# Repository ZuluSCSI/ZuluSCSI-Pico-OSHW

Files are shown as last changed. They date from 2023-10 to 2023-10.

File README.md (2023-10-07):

ZuluSCSI™ Pico Community Edition - Open Source Hardware
========================

This repository contains the KiCAD 7 schematic and PCB design files for the Pico-based ZuluSCSI™ SCSI to SD storage emulator, which is derived from the ZuluSCSI RP2040 board design. Firmware for ZuluSCSI is available at http://github.com/ZuluSCSI/ZuluSCSI-firmware.

This hardware design is licensed under the terms of the strongly reciprocal CERN OHL-S V2 license, which can be viewed in full at https://ohwr.org/cern_ohl_s_v2.txt and https://ohwr.org/cern_ohl_s_v2.pdf. 

ZuluSCSI™ is a registered trademark of Rabbit Hole Computing, and may not be used commercially without the express written consent of Rabbit Hole Computing. Individuals producing ZuluSCSI boards for personal use are hereby granted permission to use the ZuluSCSI trademark in a noncommercial capacity.

_Any_ use of the ZuluSCSI trademark in a **commercial** context requires prior written consent from Rabbit Hole Computing.

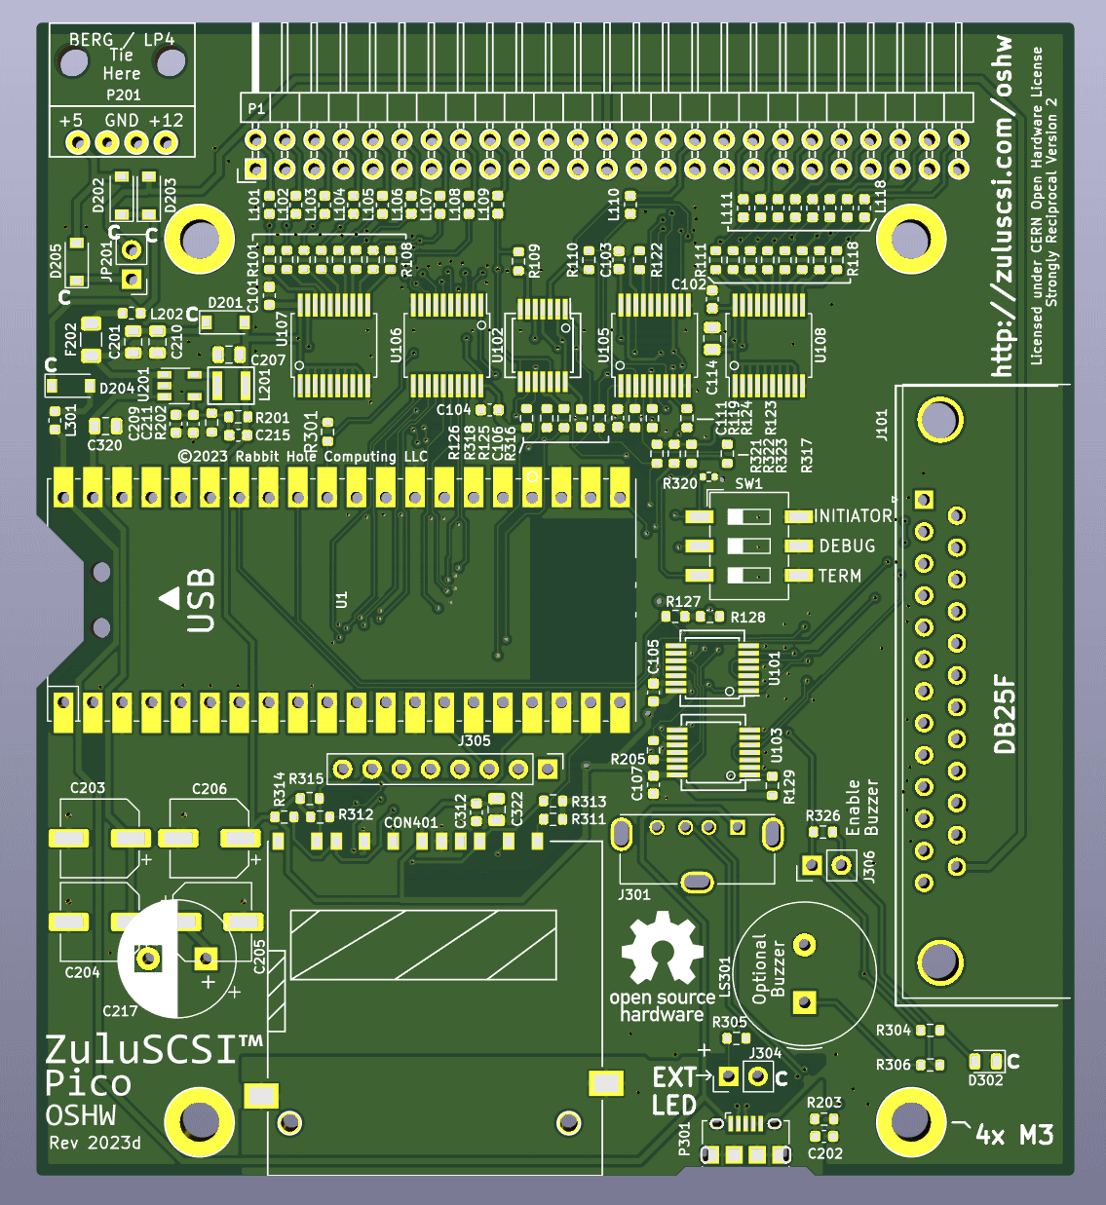
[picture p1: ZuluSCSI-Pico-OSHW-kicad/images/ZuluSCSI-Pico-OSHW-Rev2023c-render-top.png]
ZuluSCSI Pico OSHW board Render (top)


Generating fabrication files
----------------------------

The component part numbers are stored in KiCAD schematic.
Manufacturing files, including assembly BOM, can be generated using [KiKit](https://github.com/yaqwsx/KiKit).

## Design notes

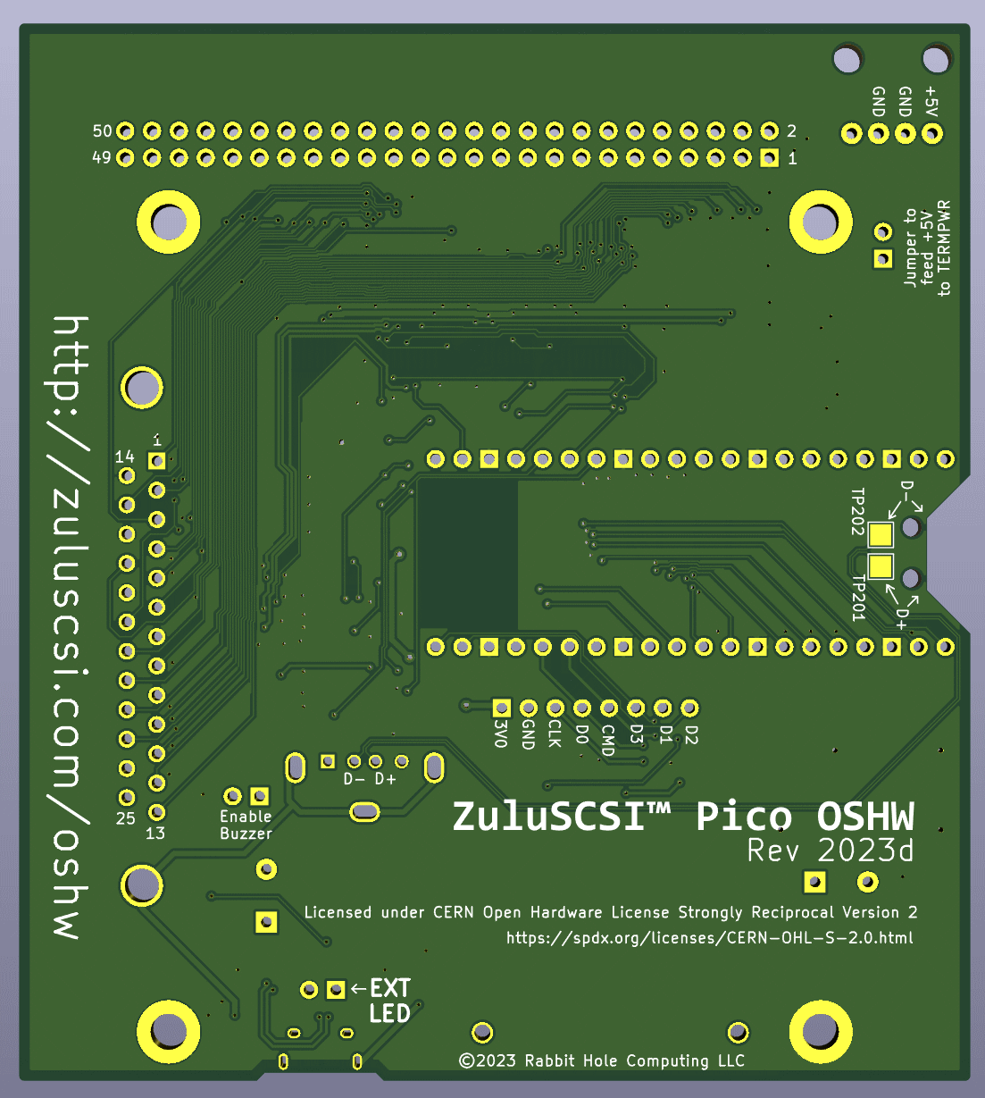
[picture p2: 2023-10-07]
ZuluSCSI-Pico-OSHW-kicad/images/ZuluSCSI-Pico-OSHW-Rev2023c-render-bottom.png

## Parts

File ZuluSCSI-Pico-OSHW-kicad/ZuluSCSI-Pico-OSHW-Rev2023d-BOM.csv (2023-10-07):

Designator | Footprint | Manufacturer P/N | Quantity | Value | LCSC P/N | Digi-Key P/N | Mouser P/N
C101, C102, C103, C104, C105, C106, C107, C202, C312 | 603 | CC0603KRX7R9BB104 | 9 | 100nF | C14663 | 311-1344-1-ND | 603-CC603KRX7R9BB104
C111, C209, C211, C215 | 603 | CL10C120JB8NNNC | 4 | 12pF | C38523 | 445-14057-1-ND | 187-CL10C120JB8NNNC
C114, C201, C207, C210, C320, C322 | 805 | CL21A106KAYNNNE | 6 | 10uF | C15850 | 1276-2891-1-ND | 187-CL21A106KAYNNNE
C203, C204, C205, C206 | CP_Elec_6.3x7.7 | RVT220UF16V67RV0015 | 4 | 220uF | C2887273 | 732-8422-1-ND | 710-865080345012
C217 | Radial through-hole D10.0mm by P5.00mm | UVY1C102MPD1TD | 1 | 1000uF | N/A | 493-14736-1-ND | 647-UVY1C102MPD1TD
CON401 | FCI 10067847-001 or SD-111 | SD-111 | 1 | SD Card Socket | C410353 | 609-3956-2-ND | 649-10067847-001RLF
D201, D202, D203, D204, D205 | SOD-123 | B5819W SL | 5 | D_Schottky | C8598 | SM5819PL-TPMSCT-ND | 833-SM5819PL-TP
D302 | 805 | SZYY0805YG | 1 | LED | C434435 | 350-2044-1-ND | 645-598-8170-107F
F202 | 1206 | JK-nSMD050-24 | 1 | 500mA Hold PTC | C369160 | 507-1802-1-ND | 530-0ZCJ0050FF2G
J101 | Optional DSUB-25 Female | D25S33E4PA00LF | 1 | N/A | N/A | 609-5879-ND | 649-D25S33E4PA00LF
J301 | Optional USB-A | Molex 105057 | 1 | N/A | N/A | WM8672-ND | 538-105057-0001
J304 | 2-pin 2.54mm Pin Header | Generic | 1 | Optional External LED header | N/A | 952-2262-ND | 855-M20-9990246
JP201 | 2-pin 2.54mm Pin Header | Generic | 0 | Optional Back Feed Jumper | N/A | 952-2262-ND | 855-M20-9990246
L101, L102, L103, L104, L105, L106, L107, L108, L109, L110, L111, L112, L113, L114, L115, L116, L117, L118, L202, L301 | 603 | GZ1608D601TF | 20 | 450mΩ ±25% 600Ω@100MHz | C1002 | 3442-GZ1608D601TFCT-ND | 815-ACML-0603H-601
L201 | 1008 | LQM2HPN2R2MG0L | 1 | 2.2uH | C86092 | 490-5114-1-ND | 81-LQM2HPN2R2MG0L
LS301 | Optional Piezo Buzzer | TDK PS1240P02BT | 1 | N/A | C76871 | 445-2525-1-ND | 810-PS1240P02BT
P1 | 50-pin right angle IDC (SCSI) | Z-231012050106 | 1 | 2X25 right angle box header | C221060 | 3M157291-ND | 30350-5002HB
P201 | Optional Floppy power connector | 171826-4 | 1 | Floppy-style BERG/LP4 | C590635 | A112643-ND | 571-1718264
P301 | Optional USB Micro-B | 10118194-0001LF | 1 | Micro USB OTG (optional) | C132563 | 609-4618-1-ND | 649-10118194-0001LF
R101, R102, R103, R104, R105, R106, R107, R108, R109, R110, R111, R112, R113, R114, R115, R116, R117, R118, R119 | 603 | 0603WAF1100T5E | 19 | 110 | C22781 | 311-4.70KHRCT-ND | 603-RC0603FR-074K7L
R122, R123, R124, R125, R301, R321, R322, R323 | 603 | 0603WAF1001T5E | 8 | 1k | C21190 | 13-AC0603FR-131KLCT-ND | 603-AC0603FR-131KL
R126, R127, R128, R129, R205, R311, R312, R313, R314, R315, R316, R317, R318 | 603 | 0603WAF4701T5E | 13 | 4k7 | C23162 | 311-4.70KHRCT-ND | 603-RC0603FR-074K7L
R201 | 603 | 0603WAF5103T5E | 1 | 510k | C23192 | 311-510KHRCT-ND | 603-RC0603FR-07510KL
R202, R203 | 603 | 0603WAF1003T5E | 2 | 100k | C25803 | 311-100KHRCT-ND | 603-RC0603FR-07100KL
R304, R305, R306 | 603 | 0603WAJ0620T5E | 3 | 62 | C25252 | 311-62.0HRCT-ND | 603-RC0603FR-0762RL
R320 | 402 | N/A | 0 | None (DNP) | N/A | N/A | N/A
SW1 | DIP slide switch, SPSTx03 | DSIC03LS-P | 1 | SW_DIP_x03 | C319040 | CT2043ST-ND | 774-2043ST
U1 | Raspberry Pi Pico (Pico, Pico H, or Pico W) | Pico | 1 |  | N/A | N/A | N/A
U101, U102, U103 | SSOP or TSSOP | SN74LVTH125PWR | 3 | 74LVT125 | C7042 | 296-8660-1-ND | 595-SN74LVTH125PWR
U105, U106, U107, U108 | SSOP or TSSOP | SN74LVTH245APWR | 4 | 74LVT245 | C7057 | 296-48966-1-ND | 595-SN74LVTH245APWR
U201 | TSOT-23-5 | LM3674MFX-ADJ/NOPB | 1 | LM3674-ADJ | C882787 | 296-43049-1-ND | 926-LM3674MFXADJNOPB

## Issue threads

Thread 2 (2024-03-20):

Expansion header

badass-boss, 2024-03-20:
Does this hardware revision offer expansion header? Is this possible to attach DAC Attack board to it?

aperezbios, 2024-03-27:
@badass-boss it does not. In order for there to be sufficient I/O's for the DAC Attack add-on board, you must be using a ZuluSCSI RP2040 (non-Pico) board, as the pinouts are slightly different. The RP2040 is a great chip, but it comes with limitations, particularly on the limited I/O front.

Closed 2024-03-27.

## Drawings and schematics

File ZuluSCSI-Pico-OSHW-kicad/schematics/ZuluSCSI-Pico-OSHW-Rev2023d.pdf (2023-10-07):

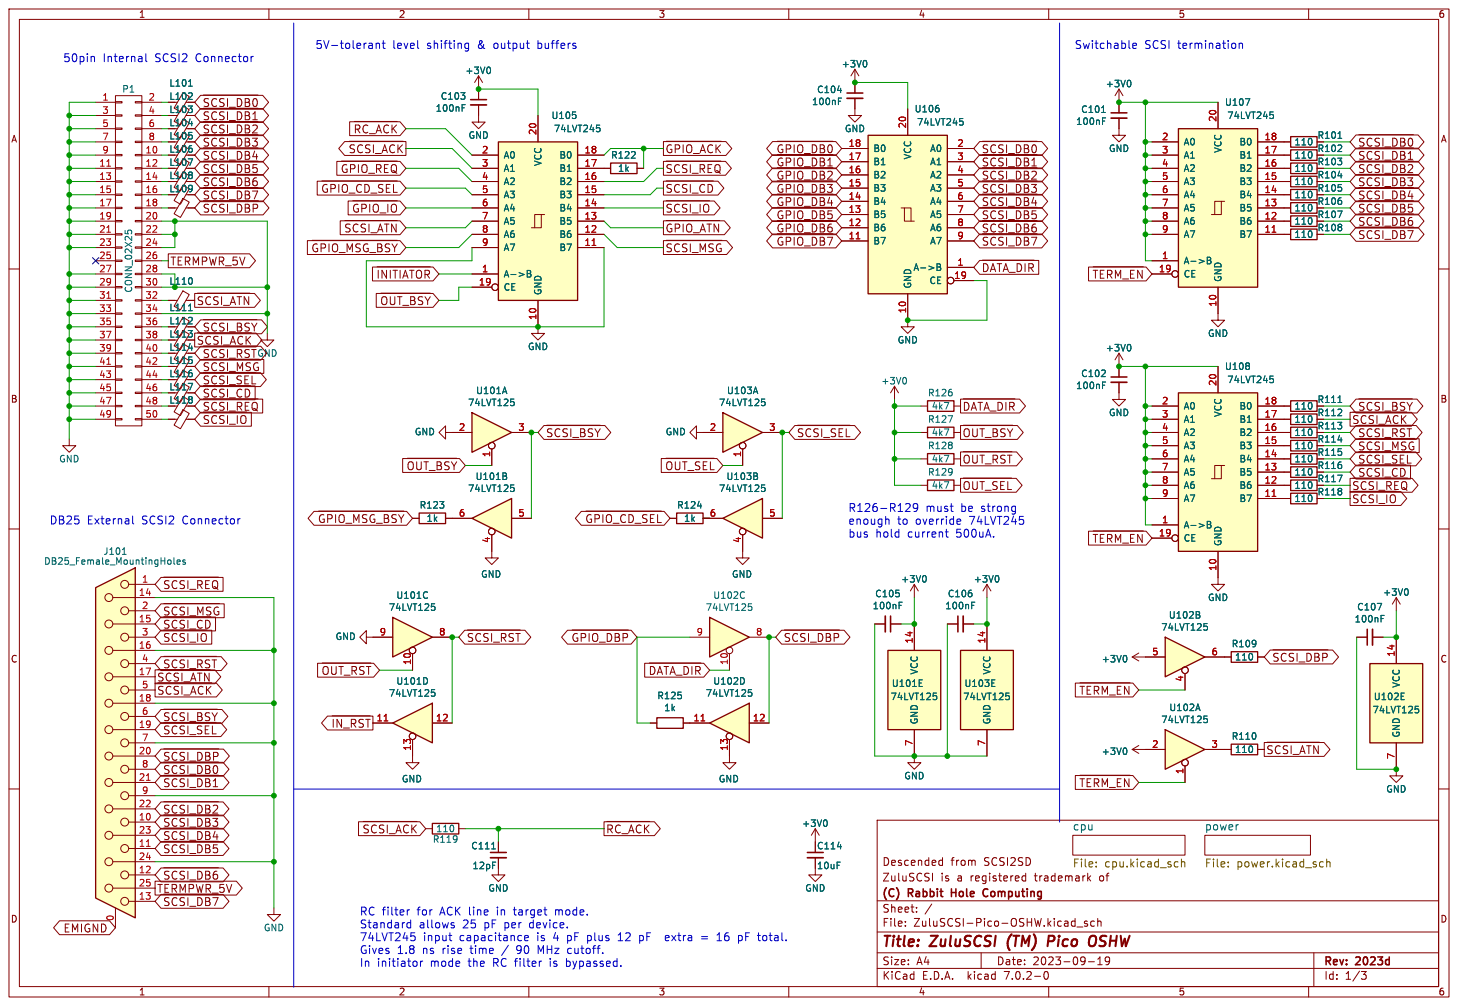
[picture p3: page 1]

Id: 1/3 Title: ZuluSCSI (TM) Pico OSHW

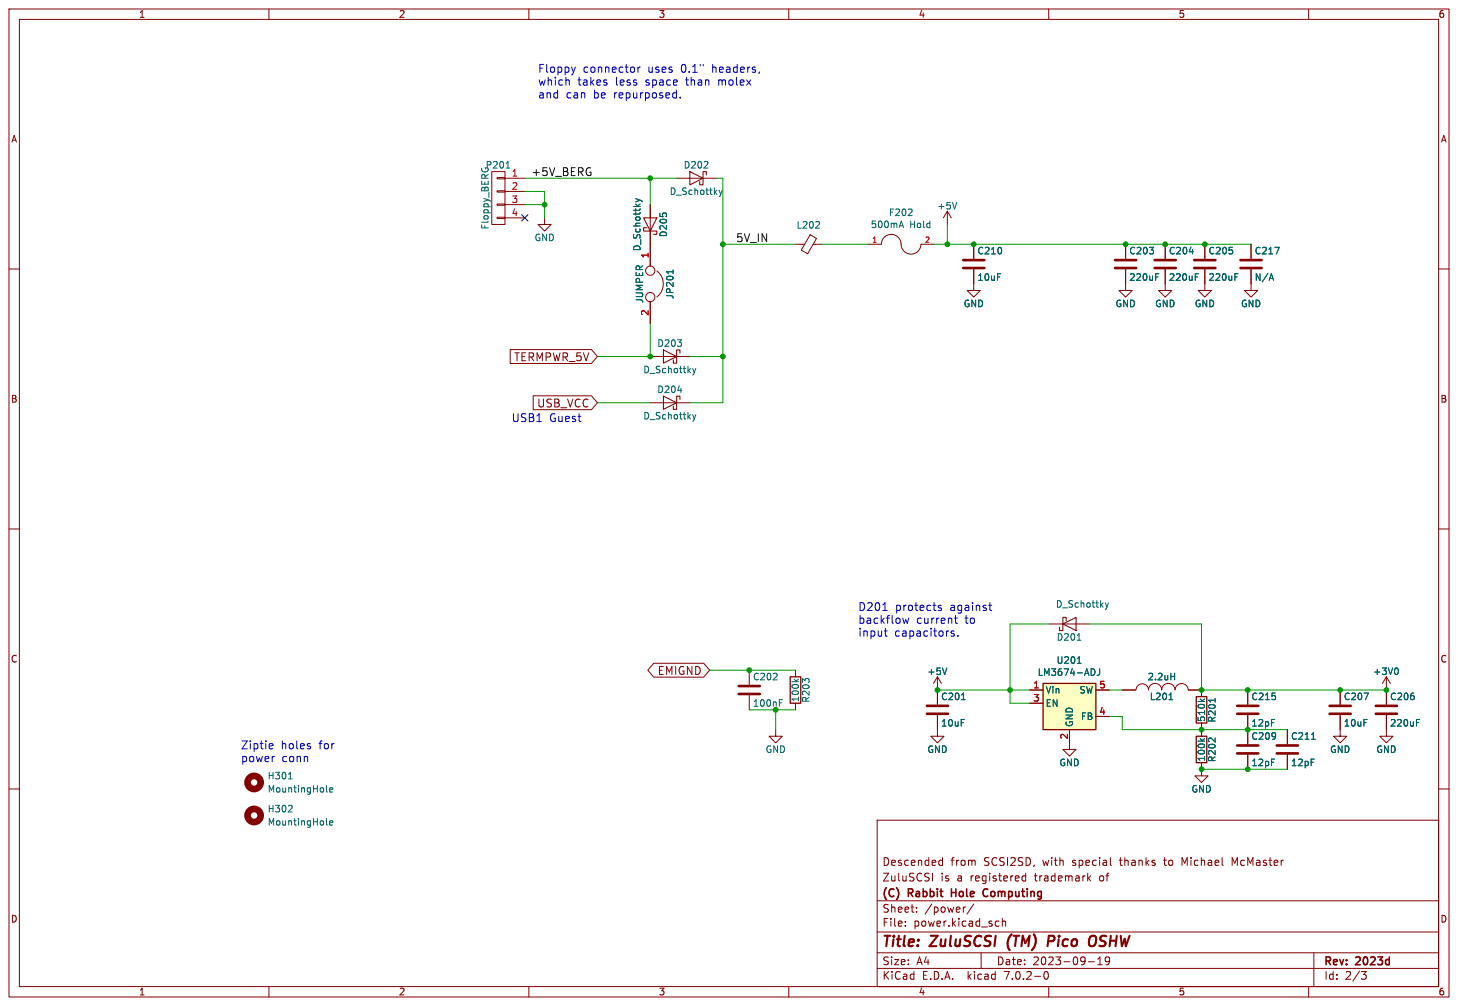
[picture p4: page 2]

D201 protects against backflow current to

Id: 2/3 Title: ZuluSCSI (TM) Pico OSHW

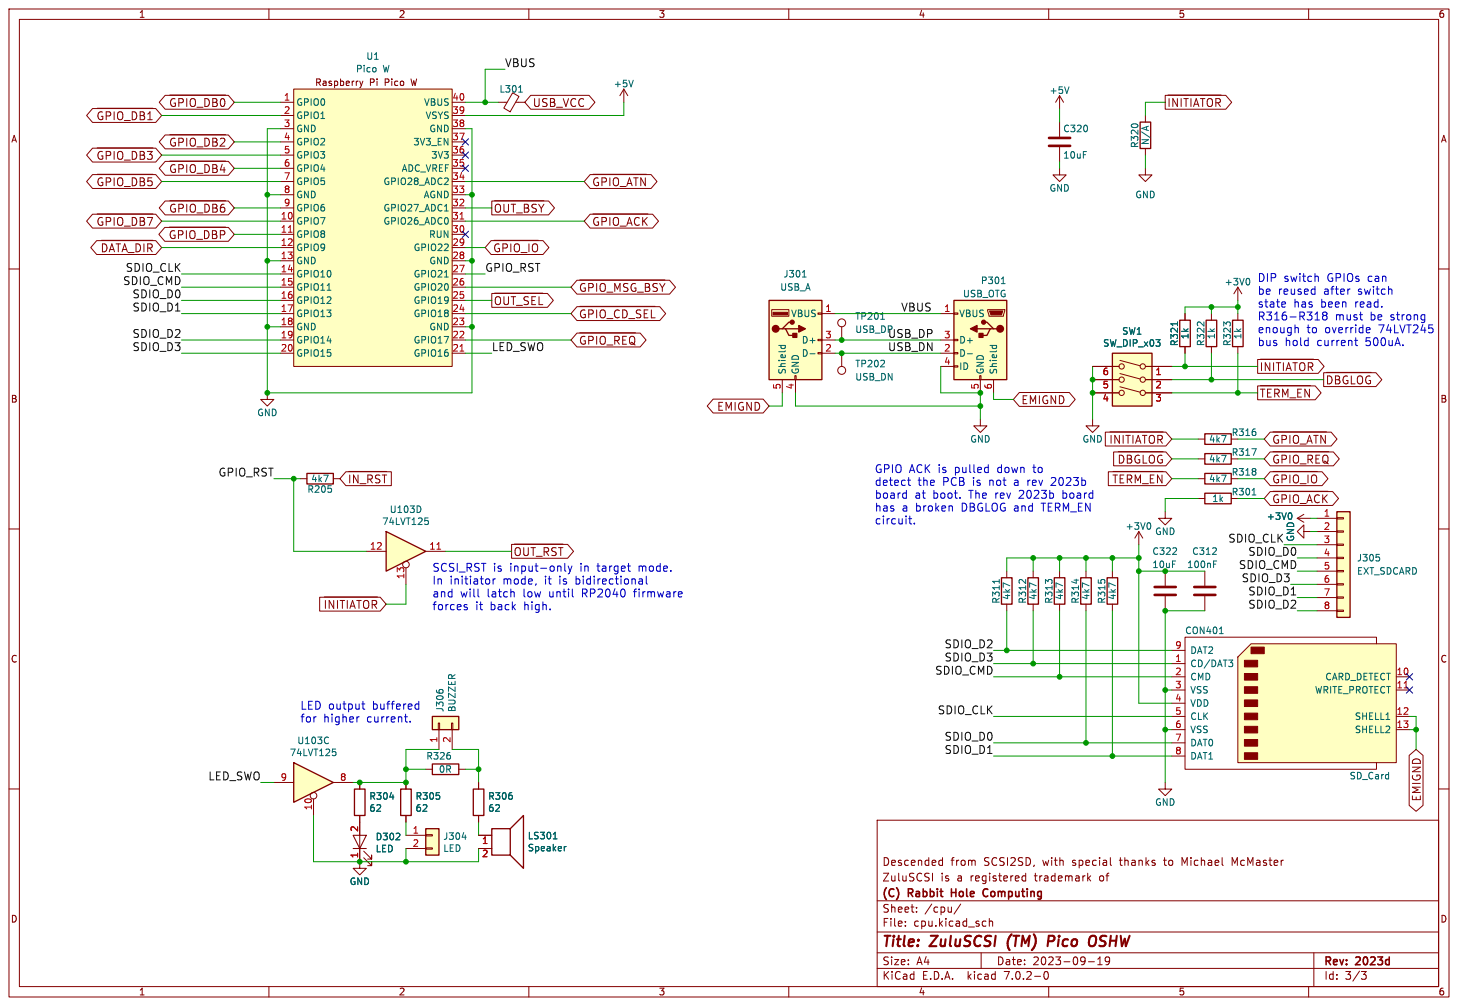
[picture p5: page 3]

SDIO_CLK DIP switch GPIOs can
be reused after switch

VBUS
USB_DP
bus hold current 500uA. GPIO ACK is pulled down to
USB_DN

detect the PCB is not a rev 2023b
board at boot. The rev 2023b board
has a broken DBGLOG and TERM_EN

circuit. LED output buffered

File: cpu.kicad_sch Sheet: /cpu/
Id: 3/3 Title: ZuluSCSI (TM) Pico OSHW

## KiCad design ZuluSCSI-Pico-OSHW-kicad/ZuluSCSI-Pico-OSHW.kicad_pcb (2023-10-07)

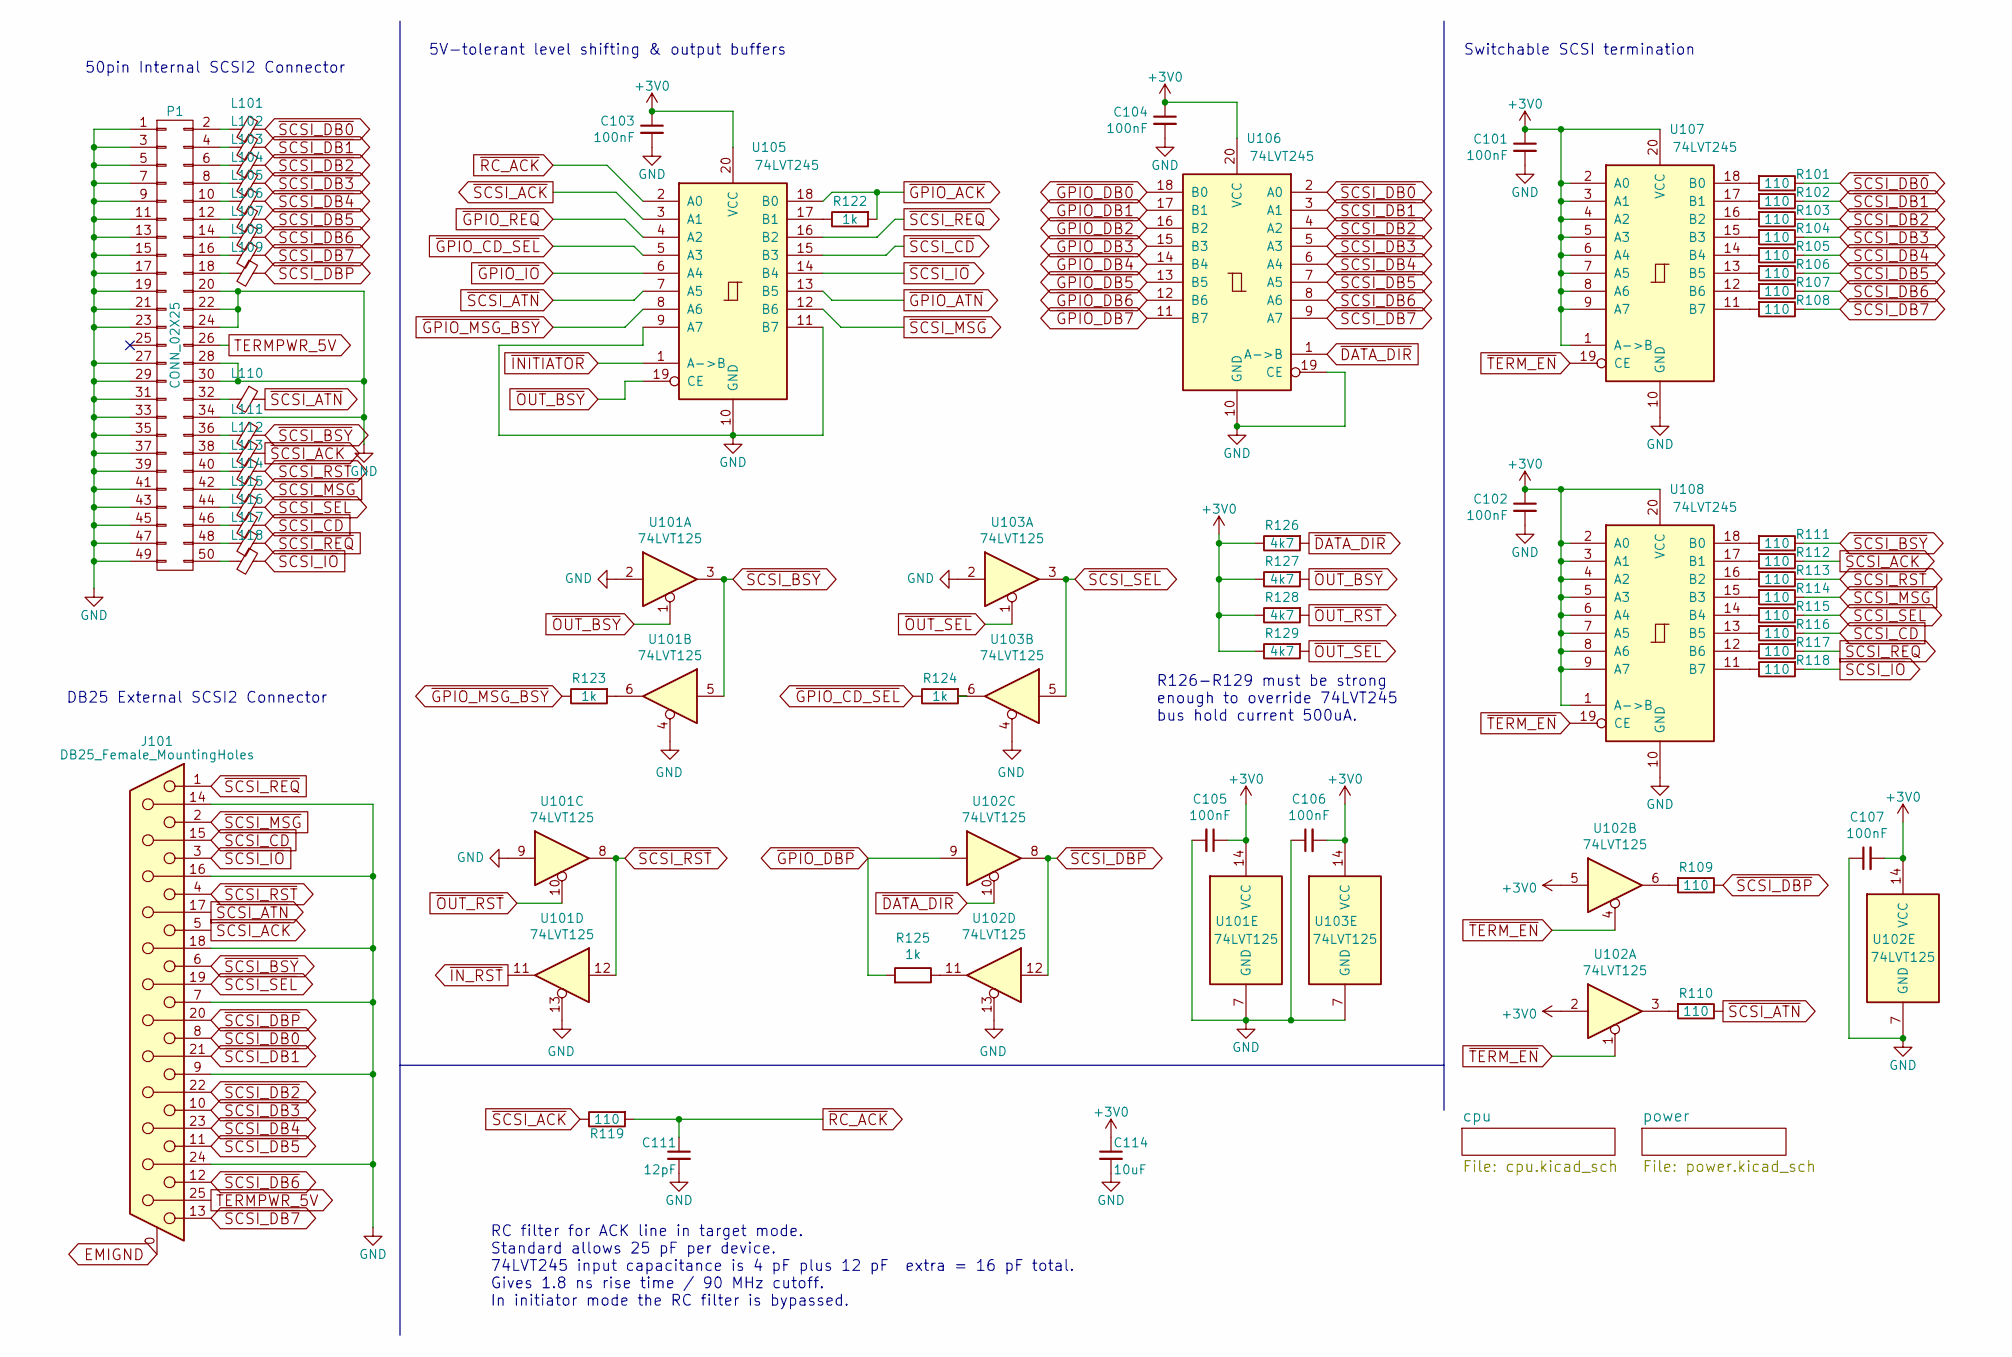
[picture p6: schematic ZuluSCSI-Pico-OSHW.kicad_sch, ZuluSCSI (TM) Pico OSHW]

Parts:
C101, C102, C103, C104, C105, C106, C107: 100nF; C_0603_1608Metric; PartNumber CL10B104KB8NNWC; LCSC C14663
C111: 12pF; C_0603_1608Metric; PartNumber C0603C120J5GAC7867; LCSC C38523
C114: 10uF; C_0805_2012Metric; PartNumber CL21A106KPFNNNG; LCSC C15850
J101: DB25_Female_MountingHoles; DSUB-25_Female_Horizontal_P2.77x2.84mm_EdgePinOffset9.90mm_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; LCSC N/A
L101, L102, L103, L104, L105, L106, L107, L108, L109, L110, L111, L112, L113, L114, L115, L116, L117, L118: Ferrite_Bead_Small; L_0603_1608Metric; PartNumber PE-0603FB601ST; LCSC C1002
P1: CONN_02X25; Pin_Header_Angled_2x25; LCSC N/A
R101, R102, R103, R104, R105, R106, R107, R108, R109, R110, R111, R112, R113, R114, R115, R116, R117, R118, R119: 110; R_0603_1608Metric; PartNumber RC0603FR-07110RL; LCSC C22781
R122, R123, R124, R125: 1k; R_0603_1608Metric; PartNumber RC0603JR-071KL; LCSC C21190
R126, R127, R128, R129: 4k7; R_0603_1608Metric; PartNumber RC0603JR-074K7L; LCSC C23162
U101, U102, U103: 74LVT125; SSOP_TSSOP-14_4.4x5mm_Pitch0.65mm_PCBWay-MaskClearance0.22mm; PartNumber 74LVTH125MTC; LCSC C7042
U105, U106, U107, U108: 74LVT245; SSOP_TSSOP-20_5.3x7.2mm_P0.65mm; PartNumber 74LVT245BBT20-13; LCSC C7057

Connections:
+3V0: C101.1, C102.1, C103.1, C104.1, C105.1, C106.2, C107.2, C114.1, R126.1, R127.1, R128.1, R129.1, U101.14 (VCC), U102.2, U102.5, U102.14 (VCC), U103.14 (VCC), U105.20 (VCC), U106.20 (VCC), U107.1 (A->B), U107.2 (A0), U107.3 (A1), U107.4 (A2), U107.5 (A3), U107.6 (A4), U107.7 (A5), U107.8 (A6), U107.9 (A7), U107.20 (VCC), U108.1 (A->B), U108.2 (A0), U108.3 (A1), U108.4 (A2), U108.5 (A3), U108.6 (A4), U108.7 (A5), U108.8 (A6), U108.9 (A7), U108.20 (VCC); also elsewhere on the board
EMIGND: J101.0 (PAD); also elsewhere on the board
GND: C101.2, C102.2, C103.2, C104.2, C105.2, C106.1, C107.1, C111.2, C114.2, J101.7, J101.9, J101.14, J101.16, J101.18, J101.24, P1.1, P1.3, P1.5, P1.7, P1.9, P1.11, P1.13, P1.15, P1.17, P1.19, P1.20, P1.21, P1.22, P1.23, P1.24, P1.27, P1.28, P1.29, P1.30, P1.31, P1.33, P1.34, P1.35, P1.37, P1.39, P1.41, P1.43, P1.45, P1.47, P1.49, U101.2, U101.4, U101.7 (GND), U101.9, U101.13, U102.7 (GND), U102.13, U103.2, U103.4, U103.7 (GND), U105.9 (A7), U105.10 (GND), U105.11 (B7), U106.10 (GND), U106.19 (CE), U107.10 (GND), U108.10 (GND); also elsewhere on the board
unnamed: L101.2, P1.2
unnamed: L102.2, P1.4
unnamed: L103.2, P1.6
unnamed: L104.2, P1.8
unnamed: L105.2, P1.10
unnamed: L106.2, P1.12
unnamed: L107.2, P1.14
unnamed: L108.2, P1.16
unnamed: L109.2, P1.18
unnamed: L110.2, P1.32
unnamed: L111.2, P1.36
unnamed: L112.2, P1.38
unnamed: L113.2, P1.40
unnamed: L114.2, P1.42
unnamed: L115.2, P1.44
unnamed: L116.2, P1.46
unnamed: L117.2, P1.48
unnamed: L118.2, P1.50
unnamed: R109.2, U102.6
unnamed: R110.2, U102.3
unnamed: R123.2, U101.6
unnamed: R124.2, U103.6
unnamed: R125.1, U102.11
unnamed: R122.1, U105.17 (B1)
unnamed: R101.2, U107.18 (B0)
unnamed: R102.2, U107.17 (B1)
unnamed: R103.2, U107.16 (B2)
unnamed: R104.2, U107.15 (B3)
unnamed: R105.2, U107.14 (B4)
unnamed: R106.2, U107.13 (B5)
unnamed: R107.2, U107.12 (B6)
unnamed: R108.2, U107.11 (B7)
unnamed: R111.2, U108.18 (B0)
unnamed: R112.2, U108.17 (B1)
unnamed: R113.2, U108.16 (B2)
unnamed: R114.2, U108.15 (B3)
unnamed: R115.2, U108.14 (B4)
unnamed: R116.2, U108.13 (B5)
unnamed: R117.1, U108.12 (B6)
unnamed: R118.1, U108.11 (B7)
TERMPWR_5V: J101.25, P1.26; also elsewhere on the board
~DATA_DIR: R126.2, U102.10, U106.1 (A->B); also elsewhere on the board
~GPIO_ACK: R122.2, U105.18 (B0); also elsewhere on the board
~GPIO_ATN: U105.13 (B5); also elsewhere on the board
~GPIO_CD_SEL: R124.1, U105.5 (A3); also elsewhere on the board
~GPIO_DB0: U106.18 (B0); also elsewhere on the board
~GPIO_DB1: U106.17 (B1); also elsewhere on the board
~GPIO_DB2: U106.16 (B2); also elsewhere on the board
~GPIO_DB3: U106.15 (B3); also elsewhere on the board
~GPIO_DB4: U106.14 (B4); also elsewhere on the board
~GPIO_DB5: U106.13 (B5); also elsewhere on the board
~GPIO_DB6: U106.12 (B6); also elsewhere on the board
~GPIO_DB7: U106.11 (B7); also elsewhere on the board
~GPIO_DBP: R125.2, U102.9; also elsewhere on the board
~GPIO_IO: U105.6 (A4); also elsewhere on the board
~GPIO_MSG_BSY: R123.1, U105.8 (A6); also elsewhere on the board
~GPIO_REQ: U105.4 (A2); also elsewhere on the board
~INITIATOR: U105.1 (A->B); also elsewhere on the board
~IN_RST: U101.11; also elsewhere on the board
~OUT_BSY: R127.2, U101.1, U105.19 (CE); also elsewhere on the board
~OUT_RST: R128.2, U101.10; also elsewhere on the board
~OUT_SEL: R129.2, U103.1; also elsewhere on the board
~RC_ACK: C111.1, R119.2, U105.2 (A0)
~SCSI_ACK: J101.5, L112.1, R112.1, R119.1, U105.3 (A1)
~SCSI_ATN: J101.17, L110.1, R110.1, U105.7 (A5)
~SCSI_BSY: J101.6, L111.1, R111.1, U101.3, U101.5
~SCSI_CD: J101.15, L116.1, R116.1, U105.15 (B3)
~SCSI_DB0: J101.8, L101.1, R101.1, U106.2 (A0)
~SCSI_DB1: J101.21, L102.1, R102.1, U106.3 (A1)
~SCSI_DB2: J101.22, L103.1, R103.1, U106.4 (A2)
~SCSI_DB3: J101.10, L104.1, R104.1, U106.5 (A3)
~SCSI_DB4: J101.23, L105.1, R105.1, U106.6 (A4)
~SCSI_DB5: J101.11, L106.1, R106.1, U106.7 (A5)
~SCSI_DB6: J101.12, L107.1, R107.1, U106.8 (A6)
~SCSI_DB7: J101.13, L108.1, R108.1, U106.9 (A7)
~SCSI_DBP: J101.20, L109.1, R109.1, U102.8, U102.12
~SCSI_IO: J101.3, L118.1, R118.2, U105.14 (B4)
~SCSI_MSG: J101.2, L114.1, R114.1, U105.12 (B6)
~SCSI_REQ: J101.1, L117.1, R117.2, U105.16 (B2)
~SCSI_RST: J101.4, L113.1, R113.1, U101.8, U101.12
~SCSI_SEL: J101.19, L115.1, R115.1, U103.3, U103.5
~TERM_EN: U102.1, U102.4, U107.19 (CE), U108.19 (CE); also elsewhere on the board

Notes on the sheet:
Switchable SCSI termination
R126-R129 must be strong enough to override 74LVT245 bus hold current 500uA.
5V-tolerant level shifting & output buffers
50pin Internal SCSI2 Connector
DB25 External SCSI2 Connector
RC filter for ACK line in target mode. Standard allows 25 pF per device. 74LVT245 input capacitance is 4 pF plus 12 pF extra = 16 pF total. Gives 1.8 ns rise time / 90 MHz cutoff. In initiator mode the RC filter is bypassed.

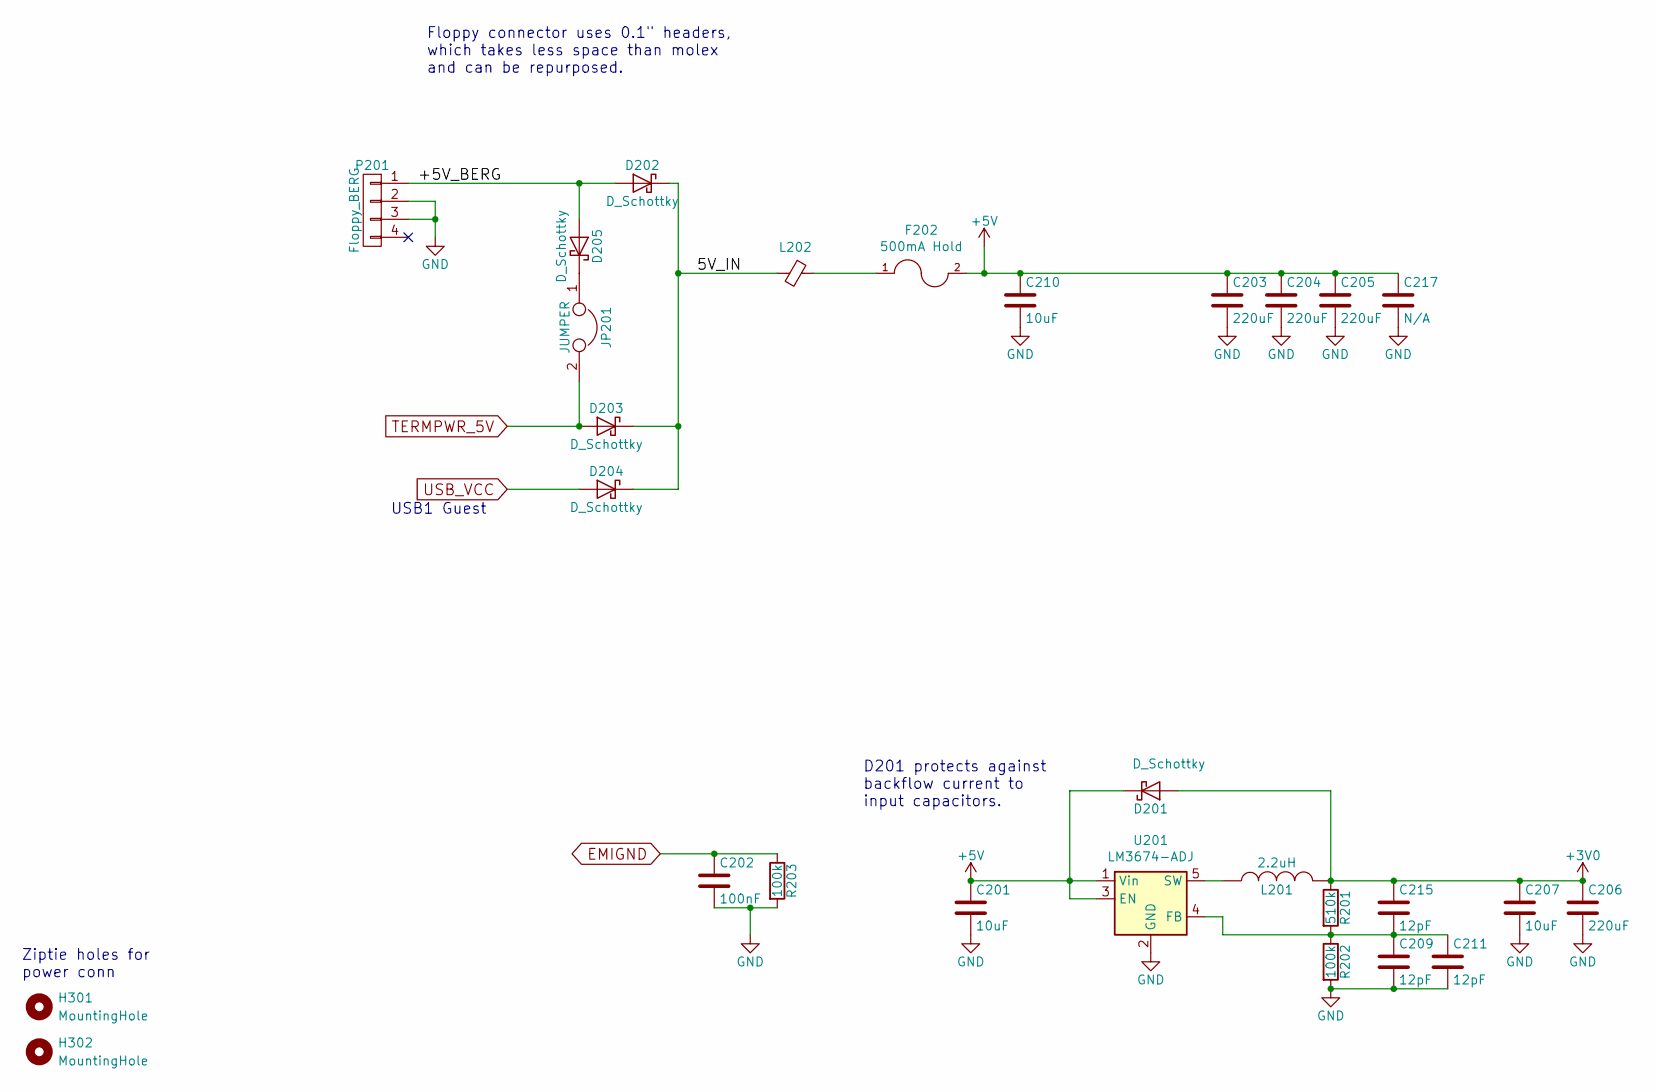
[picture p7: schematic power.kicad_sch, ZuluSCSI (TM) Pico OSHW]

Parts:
C201, C207, C210: 10uF; C_0805_2012Metric; PartNumber CL21A106KPFNNNG; LCSC C15850
C202: 100nF; C_0603_1608Metric; PartNumber CL10B104KB8NNWC; LCSC C14663
C203, C204, C205, C206: 220uF; CP_Elec_6.3x7.7; PartNumber UUD1C221MCL1GS; LCSC C2887273
C209, C211, C215: 12pF; C_0603_1608Metric; PartNumber C0603C120J5GAC7867; LCSC C38523
C217: N/A; CP_Radial_D10.0mm_P5.00mm; LCSC N/A
D201, D202, D203, D204, D205: D_Schottky; D_SOD-123; PartNumber MBRX120LF-TP; LCSC C8598
F202: 500mA Hold; Fuse_1206_3216Metric; PartNumber 0ZCJ0050FF2G; LCSC C369160
H301, H302: MountingHole; MountingHole_2.7mm_M2.5; LCSC N/A
JP201: JUMPER; PinHeader_1x02_P2.54mm_Vertical; LCSC N/A
L201: 2.2uH; Inductor_1008; PartNumber DFE252012P-2R2M=P2; LCSC C86092
L202: Ferrite_Bead_Small; L_0603_1608Metric; PartNumber PE-0603FB601ST; LCSC C1002
P201: Floppy_BERG; floppy-berg; LCSC N/A
R201: 510k; R_0603_1608Metric; PartNumber RC0603FR-07510KL; LCSC C23192
R202, R203: 100k; R_0603_1608Metric; PartNumber RC0603FR-07100KL; LCSC C25803
U201: LM3674-ADJ; TSOT-23-5; PartNumber LM3674MFX-ADJ/NOPB; LCSC C52027

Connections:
+3V0: C206.1, C207.1, C215.1, D201.2 (A), L201.2, R201.1; also elsewhere on the board
+5V: C201.1, C203.1, C204.1, C205.1, C210.1, C217.1, D201.1 (K), F202.2, U201.1 (Vin), U201.3 (EN); also elsewhere on the board
/power/5V_IN: D202.1 (K), D203.1 (K), D204.1 (K), L202.2
/power/+5V_BERG: D202.2 (A), D205.2 (A), P201.1
EMIGND: C202.1, R203.1; also elsewhere on the board
GND: C201.2, C202.2, C203.2, C204.2, C205.2, C206.2, C207.2, C209.2, C210.2, C211.2, C217.2, P201.2, P201.3, R202.2, R203.2, U201.2 (GND); also elsewhere on the board
unnamed: D205.1 (K), JP201.1
unnamed: F202.1, L202.1
unnamed: C209.1, C211.1, C215.2, R201.2, R202.1, U201.4 (FB)
unnamed: L201.1, U201.5 (SW)
TERMPWR_5V: D203.2 (A), JP201.2; also elsewhere on the board
USB_VCC: D204.2 (A); also elsewhere on the board

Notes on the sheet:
Floppy connector uses 0.1" headers, which takes less space than molex and can be repurposed.
USB1 Guest
D201 protects against backflow current to input capacitors.
Ziptie holes for power conn

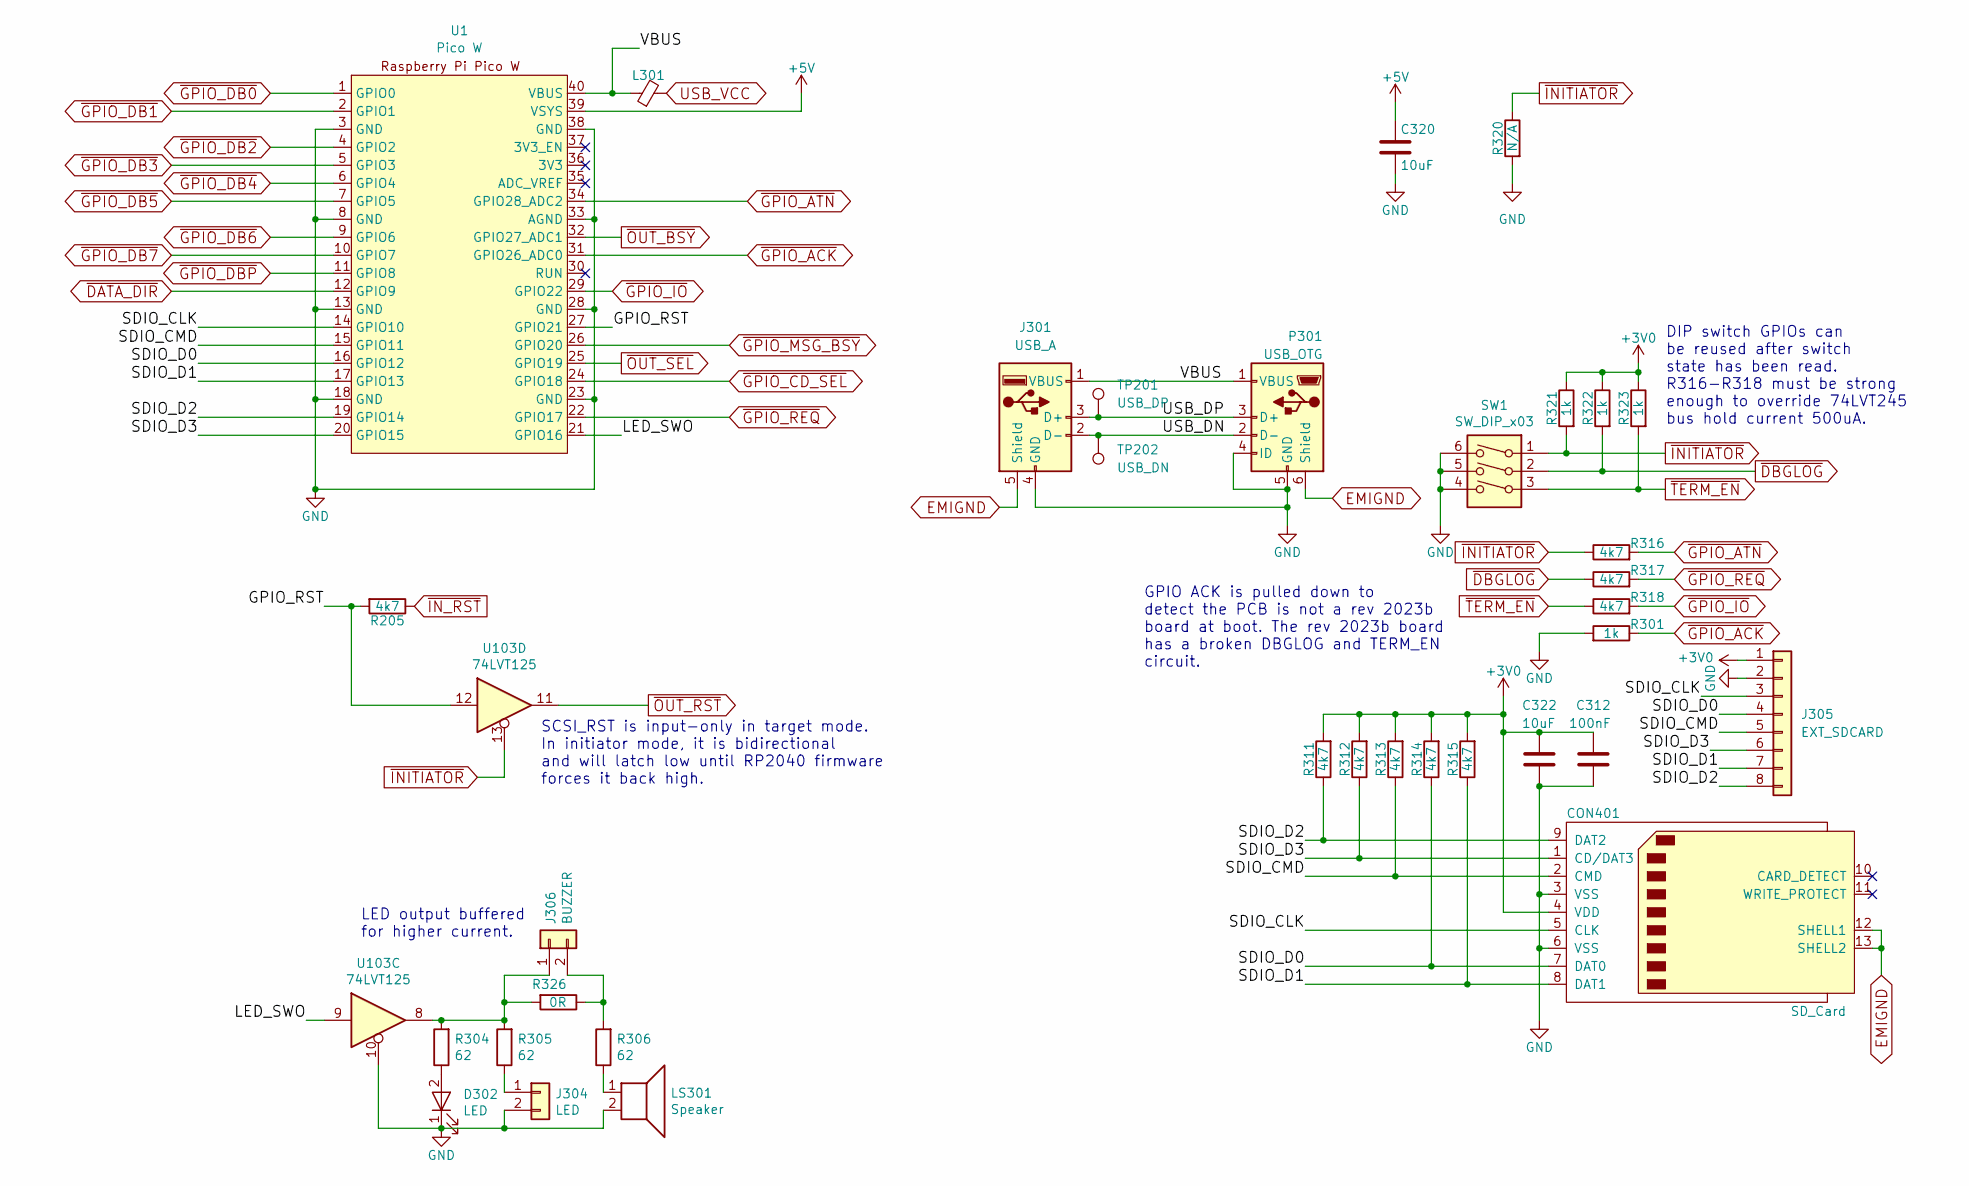
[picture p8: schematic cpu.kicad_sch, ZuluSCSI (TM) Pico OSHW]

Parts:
C312: 100nF; C_0603_1608Metric; PartNumber CL10B104KB8NNWC; LCSC C14663
C320, C322: 10uF; C_0805_2012Metric; PartNumber CL21A106KPFNNNG; LCSC C15850
CON401: SD_Card; SD-FCI-10067847-001; PartNumber 10067847-001RLF; LCSC C410353
D302: LED; LED_0805_2012Metric; PartNumber LY R976-PS-36; LCSC C434435
J301: USB_A; USB_A_Molex_105057_Vertical; LCSC N/A
J304: LED; PinHeader_1x02_P2.54mm_Vertical; LCSC N/A
J305: EXT_SDCARD; PinHeader_1x08_P2.54mm_Vertical; JLCPCB_IGNORE do not fit
J306: BUZZER; PinHeader_1x02_P2.54mm_Vertical; LCSC N/A
L301: Ferrite_Bead_Small; L_0603_1608Metric; PartNumber PE-0603FB601ST; LCSC C1002
LS301: Speaker; Buzzer_TDK_PS1240P02BT_D12.2mm_H6.5mm; LCSC N/A
P301: USB_OTG; USB_Micro-B_Amphenol_10118194_Horizontal; PartNumber 10118194-0001LF; LCSC C132563
R205, R311, R312, R313, R314, R315, R316, R317, R318: 4k7; R_0603_1608Metric; PartNumber RC0603JR-074K7L; LCSC C23162
R301, R321, R322, R323: 1k; R_0603_1608Metric; PartNumber RC0603JR-071KL; LCSC C21190
R304, R305, R306: 62; R_0603_1608Metric; PartNumber RC0603FR-0762RL; LCSC C25252
R320: N/A; R_0402_1005Metric; LCSC N/A
R326: 0R; R_0603_1608Metric; LCSC N/A
SW1: SW_DIP_x03; SW_DIP_SPSTx03_Slide_6.7x9.18mm_W8.61mm_P2.54mm_LowProfile; PartNumber 219-3MSTR; LCSC C319040
TP201: USB_DP; TestPoint_Pad_2.0x2.0mm; LCSC N/A
TP202: USB_DN; TestPoint_Pad_2.0x2.0mm; LCSC N/A
U1: Pico W; RPi_Pico_W_SMD_TH; LCSC N/A
U103: 74LVT125; SSOP_TSSOP-14_4.4x5mm_Pitch0.65mm_PCBWay-MaskClearance0.22mm; PartNumber 74LVTH125MTC; LCSC C7042

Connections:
+3V0: C312.2, C322.2, CON401.4 (VDD), J305.1, R311.2, R312.2, R313.2, R314.2, R315.2, R321.1, R322.1, R323.1; also elsewhere on the board
+5V: C320.1, U1.39 (VSYS); also elsewhere on the board
/cpu/GPIO_RST: R205.2, U1.27 (GPIO21), U103.12
/cpu/LED_SWO: U1.21 (GPIO16), U103.9
/cpu/SDIO_CLK: CON401.5 (CLK), J305.3, U1.14 (GPIO10)
/cpu/SDIO_CMD: CON401.2 (CMD), J305.5, R313.1, U1.15 (GPIO11)
/cpu/SDIO_D0: CON401.7 (DAT0), J305.4, R314.1, U1.16 (GPIO12)
/cpu/SDIO_D1: CON401.8 (DAT1), J305.7, R315.1, U1.17 (GPIO13)
/cpu/SDIO_D2: CON401.9 (DAT2), J305.8, R311.1, U1.19 (GPIO14)
/cpu/SDIO_D3: CON401.1 (CD/DAT3), J305.6, R312.1, U1.20 (GPIO15)
/cpu/USB_DN: J301.2 (D-), P301.2 (D-), TP202.1
/cpu/USB_DP: J301.3 (D+), P301.3 (D+), TP201.1
/cpu/VBUS: J301.1 (VBUS), L301.1, P301.1 (VBUS), U1.40 (VBUS)
EMIGND: CON401.12 (SHELL1), CON401.13 (SHELL2), J301.5 (Shield), P301.6 (Shield); also elsewhere on the board
GND: C312.1, C320.2, C322.1, CON401.3 (VSS), CON401.6 (VSS), D302.1 (K), J301.4 (GND), J304.2, J305.2, LS301.2, P301.4 (ID), P301.5 (GND), R301.2, R320.2, SW1.4, SW1.5, SW1.6, U1.3 (GND), U1.8 (GND), U1.13 (GND), U1.18 (GND), U1.23 (GND), U1.28 (GND), U1.33 (AGND), U1.38 (GND), U103.10; also elsewhere on the board
unnamed: D302.2 (A), R304.1
unnamed: J304.1, R305.1
unnamed: J306.1, R304.2, R305.2, R326.2, U103.8
unnamed: J306.2, R306.2, R326.1
unnamed: LS301.1, R306.1
USB_VCC: L301.2; also elsewhere on the board
~DATA_DIR: U1.12 (GPIO9); also elsewhere on the board
~DBGLOG: R317.1, R322.2, SW1.2
~GPIO_ACK: R301.1, U1.31 (GPIO26_ADC0); also elsewhere on the board
~GPIO_ATN: R316.2, U1.34 (GPIO28_ADC2); also elsewhere on the board
~GPIO_CD_SEL: U1.24 (GPIO18); also elsewhere on the board
~GPIO_DB0: U1.1 (GPIO0); also elsewhere on the board
~GPIO_DB1: U1.2 (GPIO1); also elsewhere on the board
~GPIO_DB2: U1.4 (GPIO2); also elsewhere on the board
~GPIO_DB3: U1.5 (GPIO3); also elsewhere on the board
~GPIO_DB4: U1.6 (GPIO4); also elsewhere on the board
~GPIO_DB5: U1.7 (GPIO5); also elsewhere on the board
~GPIO_DB6: U1.9 (GPIO6); also elsewhere on the board
~GPIO_DB7: U1.10 (GPIO7); also elsewhere on the board
~GPIO_DBP: U1.11 (GPIO8); also elsewhere on the board
~GPIO_IO: R318.2, U1.29 (GPIO22); also elsewhere on the board
~GPIO_MSG_BSY: U1.26 (GPIO20); also elsewhere on the board
~GPIO_REQ: R317.2, U1.22 (GPIO17); also elsewhere on the board
~INITIATOR: R316.1, R320.1, R321.2, SW1.1, U103.13; also elsewhere on the board
~IN_RST: R205.1; also elsewhere on the board
~OUT_BSY: U1.32 (GPIO27_ADC1); also elsewhere on the board
~OUT_RST: U103.11; also elsewhere on the board
~OUT_SEL: U1.25 (GPIO19); also elsewhere on the board
~TERM_EN: R318.1, R323.2, SW1.3; also elsewhere on the board

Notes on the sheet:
GPIO ACK is pulled down to detect the PCB is not a rev 2023b board at boot. The rev 2023b board has a broken DBGLOG and TERM_EN circuit.
DIP switch GPIOs can be reused after switch state has been read. R316-R318 must be strong enough to override 74LVT245 bus hold current 500uA.
SCSI_RST is input-only in target mode. In initiator mode, it is bidirectional and will latch low until RP2040 firmware forces it back high.
LED output buffered for higher current.

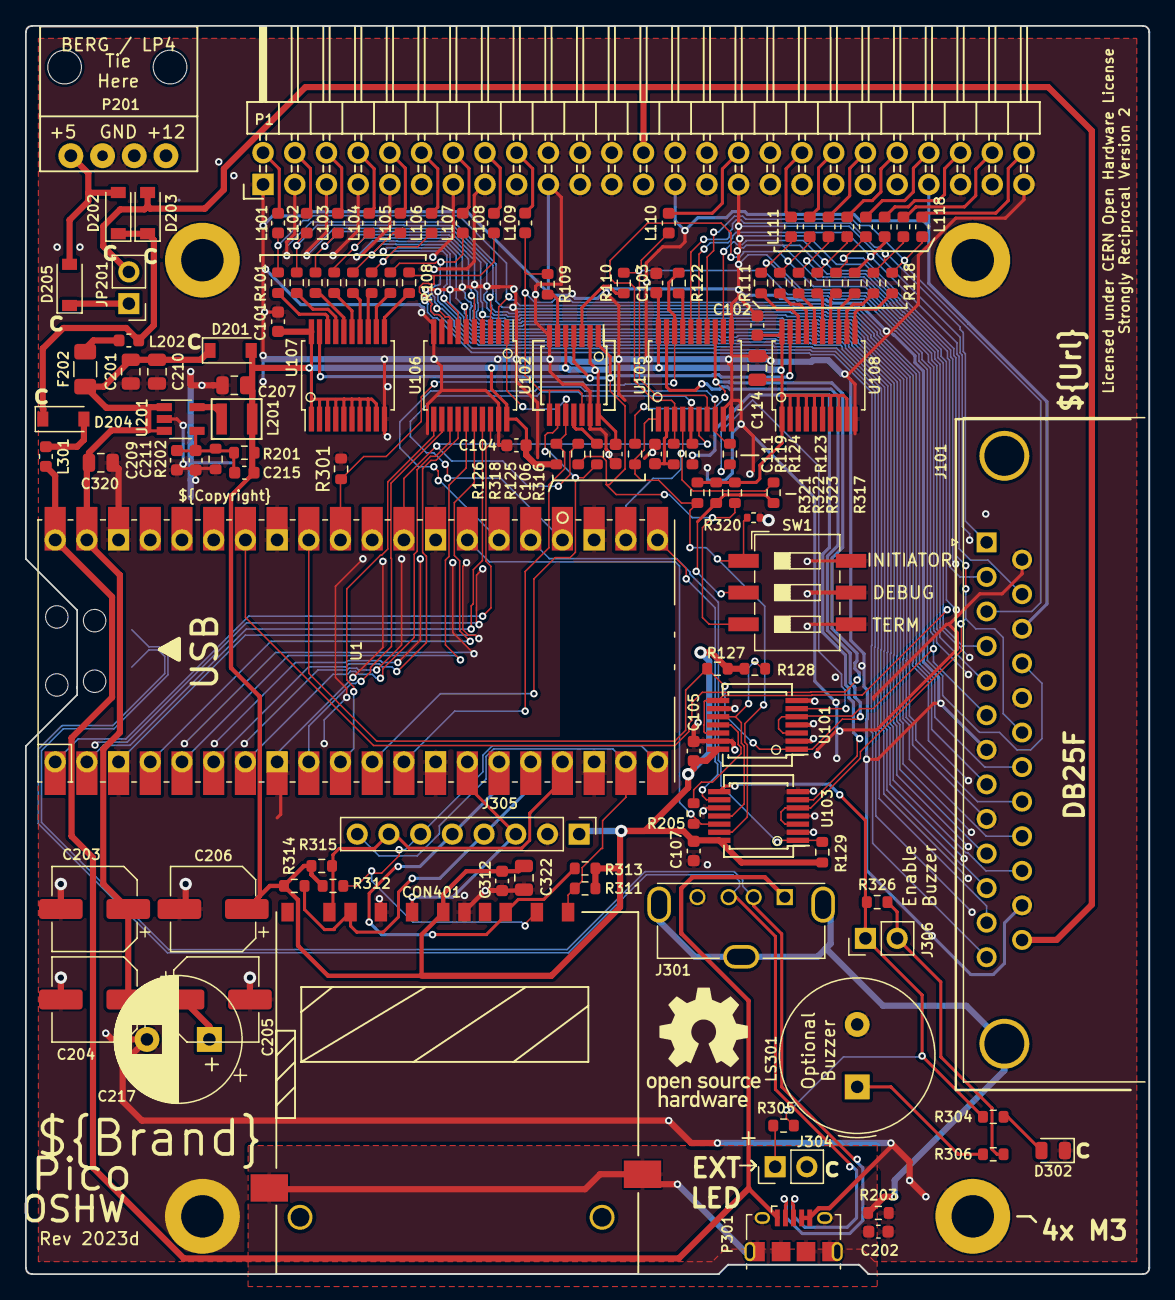
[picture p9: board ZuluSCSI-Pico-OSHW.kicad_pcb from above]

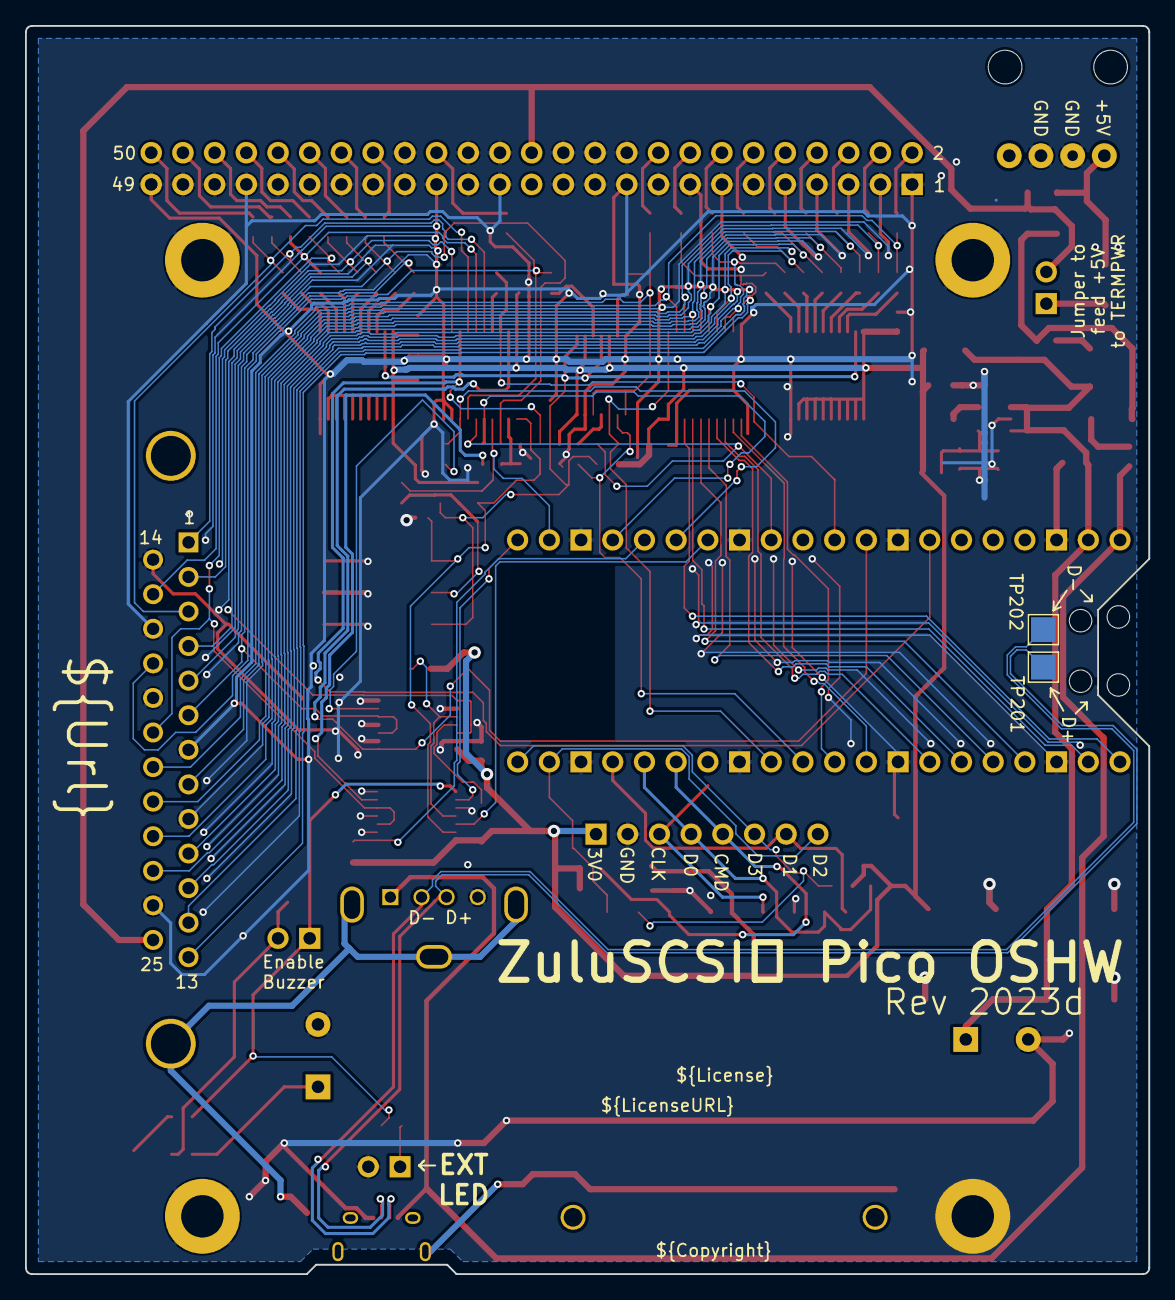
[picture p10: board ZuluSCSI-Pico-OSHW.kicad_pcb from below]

Board: 2 copper layers, 90.0 x 100.0 mm, 125 parts (2 on the bottom side), 110 nets.

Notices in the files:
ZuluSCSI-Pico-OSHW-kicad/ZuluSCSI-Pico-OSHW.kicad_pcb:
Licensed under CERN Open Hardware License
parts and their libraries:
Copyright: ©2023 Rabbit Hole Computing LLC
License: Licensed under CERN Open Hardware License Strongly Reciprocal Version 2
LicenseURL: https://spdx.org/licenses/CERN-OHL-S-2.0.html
